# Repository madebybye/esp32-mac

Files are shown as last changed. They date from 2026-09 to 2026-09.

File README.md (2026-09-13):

# ESP32 Mac

A mini retro-Macintosh enclosure for the Waveshare
[ESP32-S3-Touch-AMOLED-1.8](https://www.waveshare.com/esp32-s3-touch-amoled-1.8.htm), designed in Fusion 360 and
printed in two parts with no hardware.

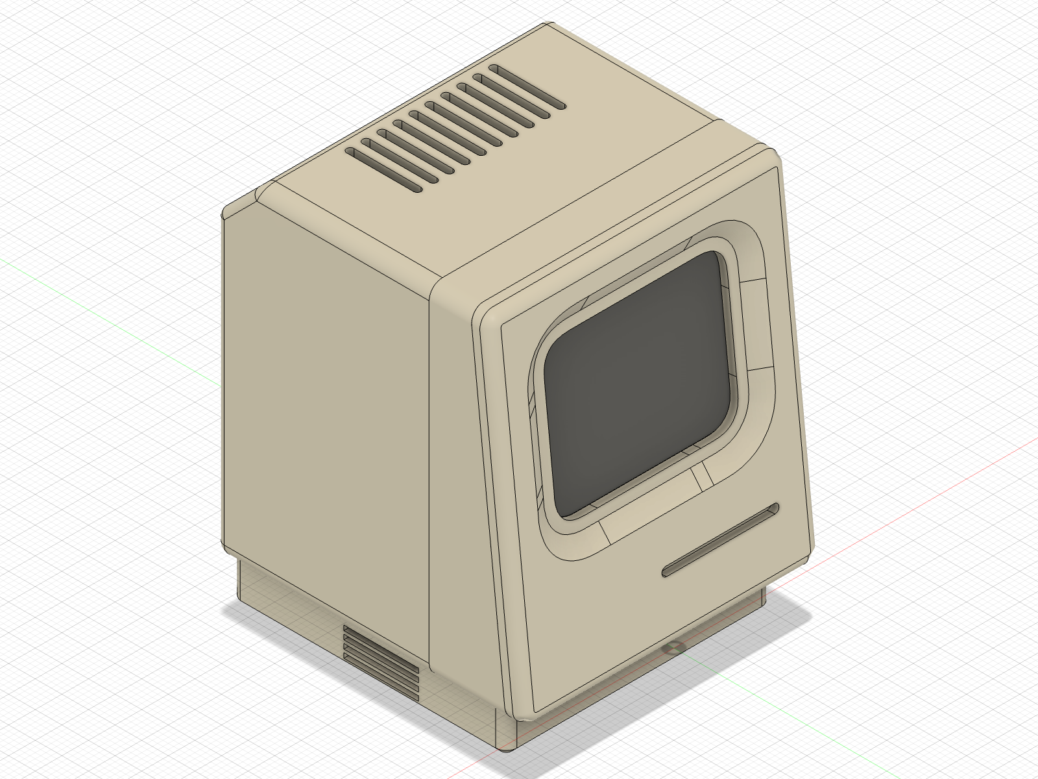
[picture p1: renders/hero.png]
ESP32 Mac


The board stays in its own case and drops into a pocket from the front, screen outwards. A separate face plate
presses onto six integrated pins (a dab of glue makes it permanent). A normal iPhone USB-C cable runs down a chute
inside the body and out through the foot, so nothing shows at the back. Warm air rises from behind the board through
a duct to the vent slots on top, and two grooves link the case's speaker and mic holes to the same duct.

## What you need

- The Waveshare ESP32-S3-Touch-AMOLED-1.8, in the case it ships in
- A normal iPhone USB-C cable (the Apple USB-C charge cable that comes with the phone). The plug cavity and chute
  are sized around its slim straight plug and thin cable, so bulkier or right-angle plugs may not fit.
- Optionally a dab of glue for the face plate

| | |
|---|---|
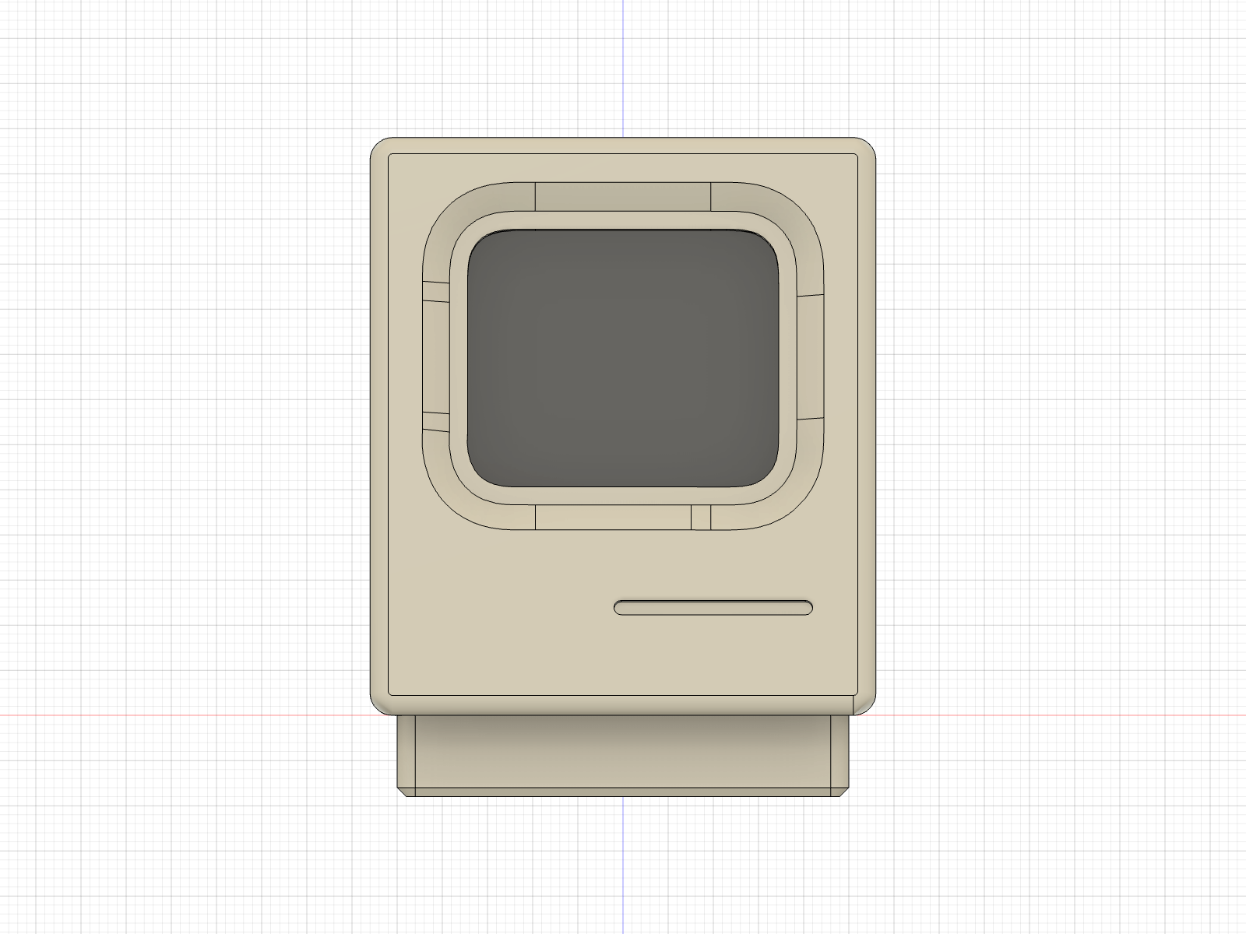
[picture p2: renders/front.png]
Front
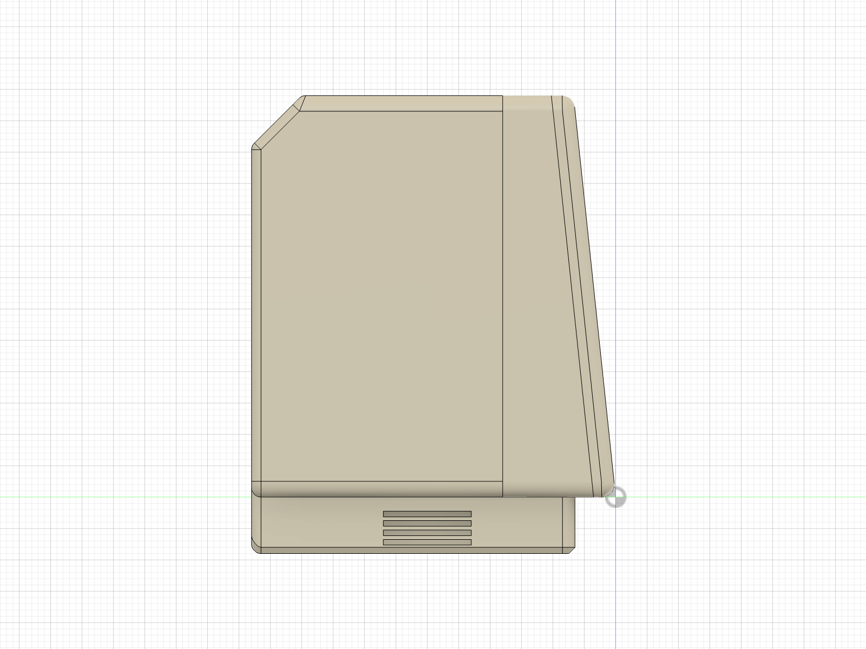
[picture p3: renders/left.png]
Side
|  |  |
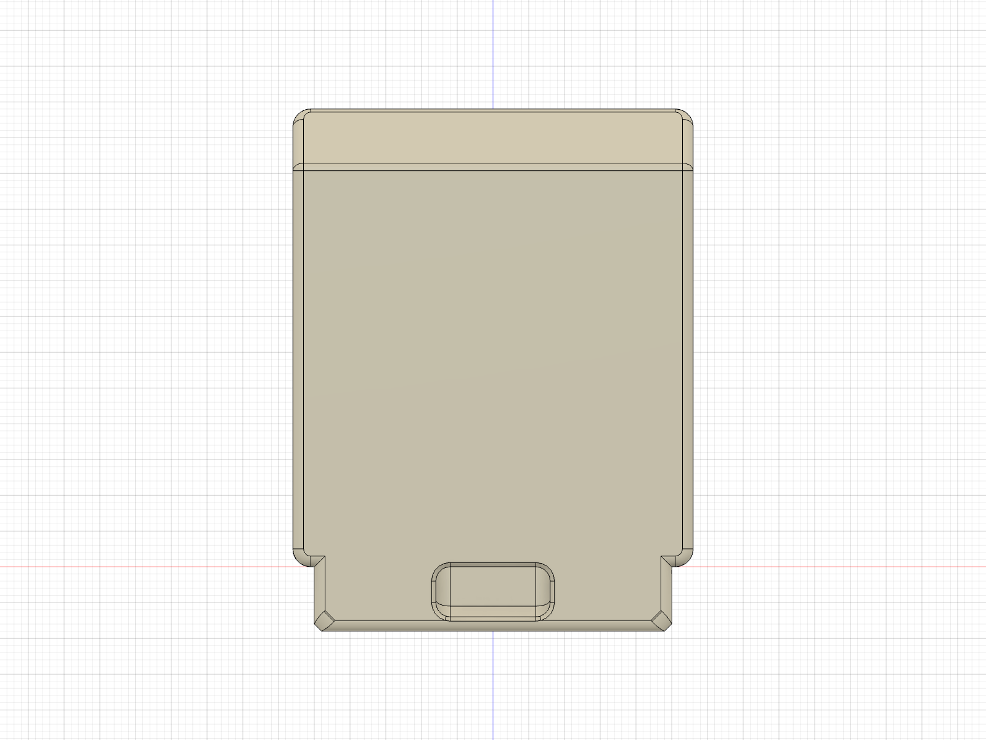
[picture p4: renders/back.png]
Back
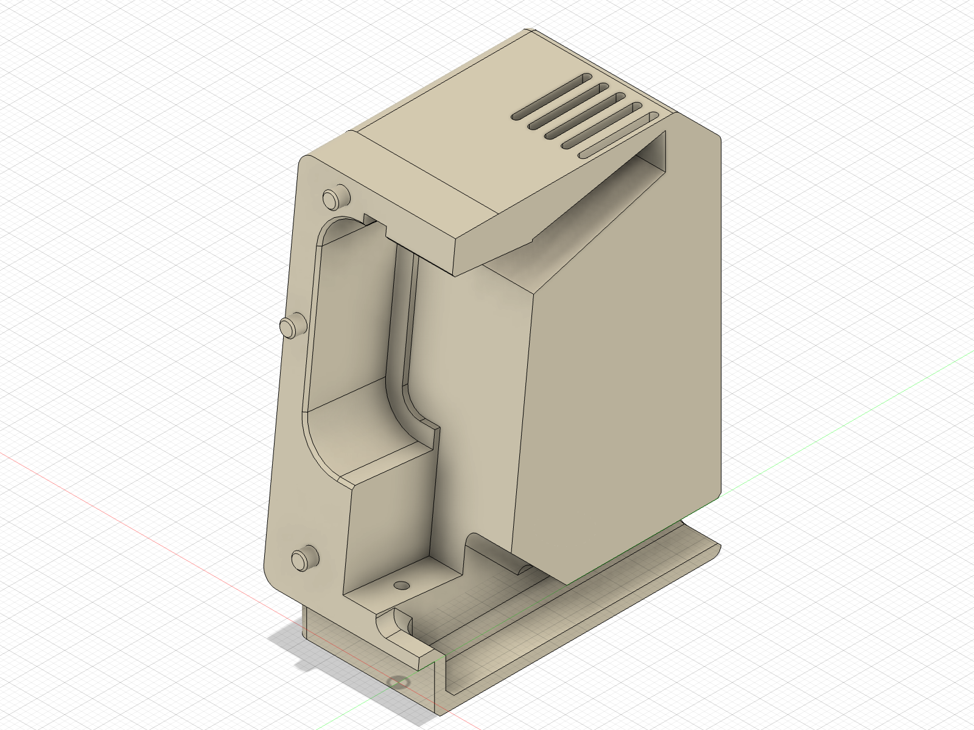
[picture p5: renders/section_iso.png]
Section
|  |  |

## Files

- `stl/` - print-ready `MiniMac_Body`, `MiniMac_FacePlate` and `MiniMac_FitGauge`
- `step/` - the same three parts as STEP
- `MiniMac.f3d` - the Fusion 360 design (it includes Waveshare's board model, imported from their wiki)
- `scripts/` - the Fusion API scripts that generate everything from one parameter block ([details](scripts/README.md))
- `renders/` - views, sections and a four-view sheet per part

## Printing

| Part | Orientation | Notes |
|---|---|---|
| Body | rear face down | 10-15 % infill, 5-6 top layers, supports on (tree) |
| FacePlate | face up | no supports; iron the top layer if you can |
| FitGauge | flat | 6 mm slab with the pocket and pins; print it first to check the fit |

0.12-0.16 mm layers, 3-4 walls. The body is 56 x 64 x 58 mm on a 9 mm foot, 73 mm tall overall.

The body needs supports: there is one internal overhang that won't print cleanly without them. Use tree supports if
your slicer has them. The face plate and the gauge print without supports.

The pocket is 45.4 x 37.7 mm for a case that measures 44.9 x 37.3, sized for a printer that comes out about 0.25 mm
tight per side. If the board is loose or won't go in, change `POCKET_W` and `POCKET_H` in `scripts/build.py` and
reprint the gauge.

## Assembly

Use a normal iPhone USB-C cable (see [What you need](#what-you-need)).

1. Feed the far end of the cable from the plug cavity down the chute, through the foot and out of the back.
2. Drop the board into the pocket with the screen facing outwards, towards the face plate.
3. Reach into the cavity and push the USB-C plug up into the socket.
4. Press the face plate onto the pins.

The board mounts landscape with its USB-C edge down, so rotate the UI 90 degrees in firmware.

## Rebuilding the model

`scripts/build.py` regenerates all three parts from the parameters at its top: pocket size, wall thicknesses, vents,
cable route. It needs Fusion 360 with Waveshare's 3D model imported. Download `ESP32-S3-Touch-AMOLED-1.8-3D.zip`
from the [Waveshare wiki](https://www.waveshare.com/wiki/ESP32-S3-Touch-AMOLED-1.8), unzip the `.stp` into
`reference/`, then run `import_step.py`, `build.py`, `checks.py` and `export.py` in that order from Fusion's Scripts
panel.

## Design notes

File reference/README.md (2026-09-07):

Waveshare's 3D model of the board goes here and is not included in this repository.

Download `ESP32-S3-Touch-AMOLED-1.8-3D.zip` from the resources section of the
[Waveshare wiki](https://www.waveshare.com/wiki/ESP32-S3-Touch-AMOLED-1.8) and unzip
`ESP32-S3-Touch-AMOLED-1.8-3D.stp` into this folder. `scripts/import_step.py` imports it.

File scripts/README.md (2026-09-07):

Fusion 360 API scripts. Each defines `run(context)`; run them from Fusion's Scripts and Add-Ins panel (or through a
Fusion MCP server, in which case define `__file__` first so the scripts can find the repo folder).

1. `import_step.py` - imports `../reference/ESP32-S3-Touch-AMOLED-1.8-3D.stp` (Waveshare's board model) into an empty design.
2. `build.py` - rebuilds FacePlate, Body and FitGauge from the parameters at its top. Safe to re-run: it deletes the
   previous parts, re-places the board and rebuilds.
3. `checks.py` - interference and ray-cast checks. One interference is expected: the pocket is cut 0.4 mm shallower
   than the case, so the face plate holds the board on the pocket's floor rim.
4. `export.py` - writes `../MiniMac.f3d`, `../stl/MiniMac_<part>.stl` and `../step/MiniMac_<part>.step`.

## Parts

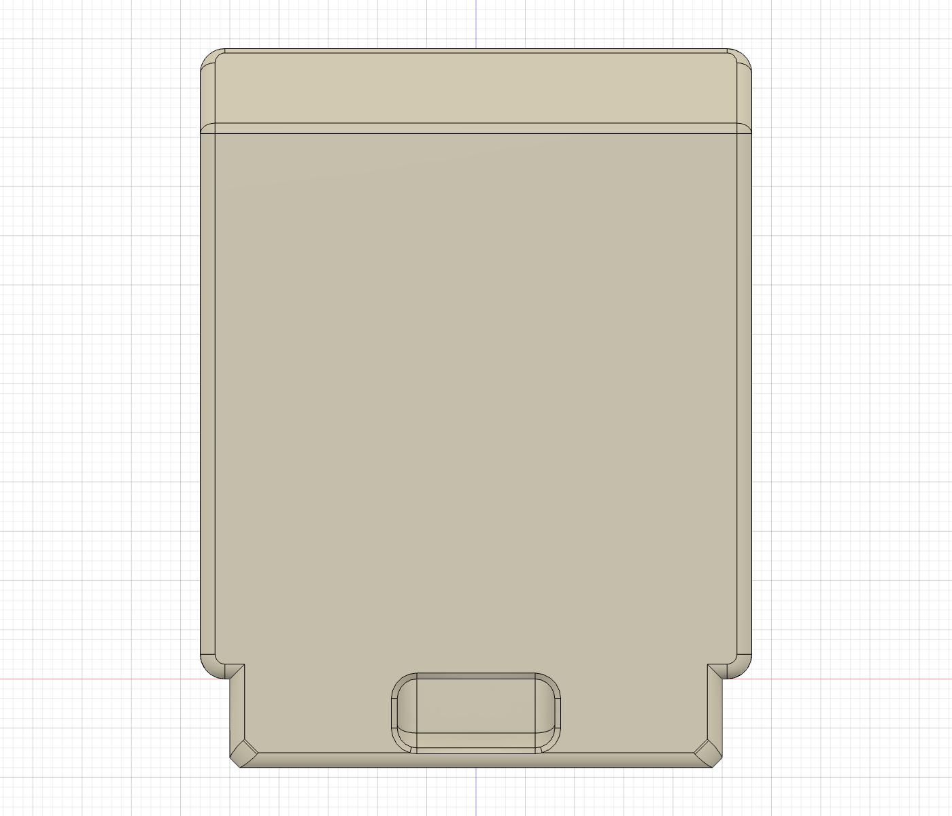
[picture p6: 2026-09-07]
renders/parts/Body_back.png

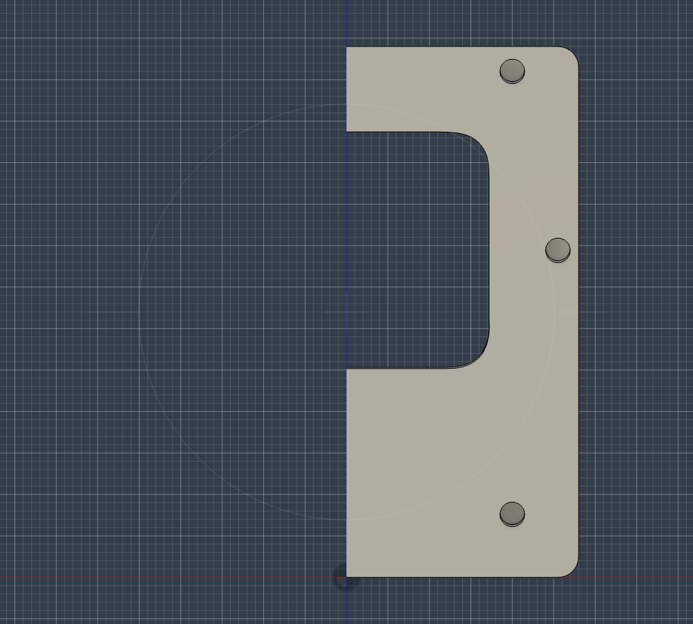
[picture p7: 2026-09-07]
renders/parts/FacePlate_back.png

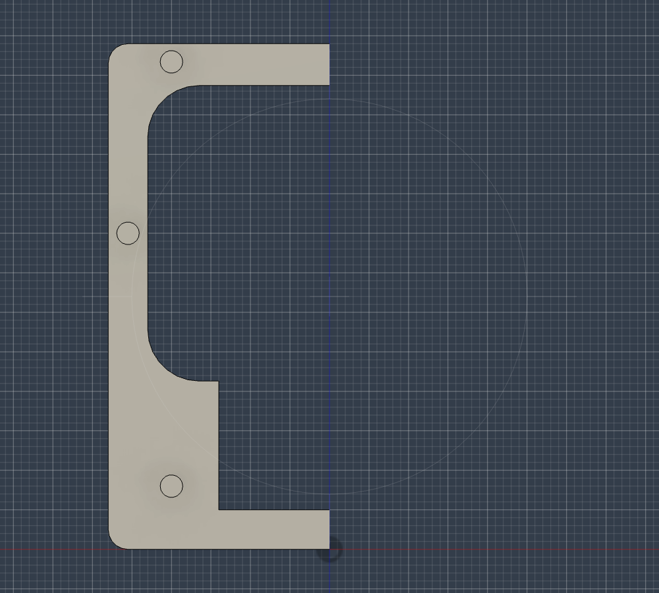
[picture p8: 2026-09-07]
renders/parts/FitGauge_front.png

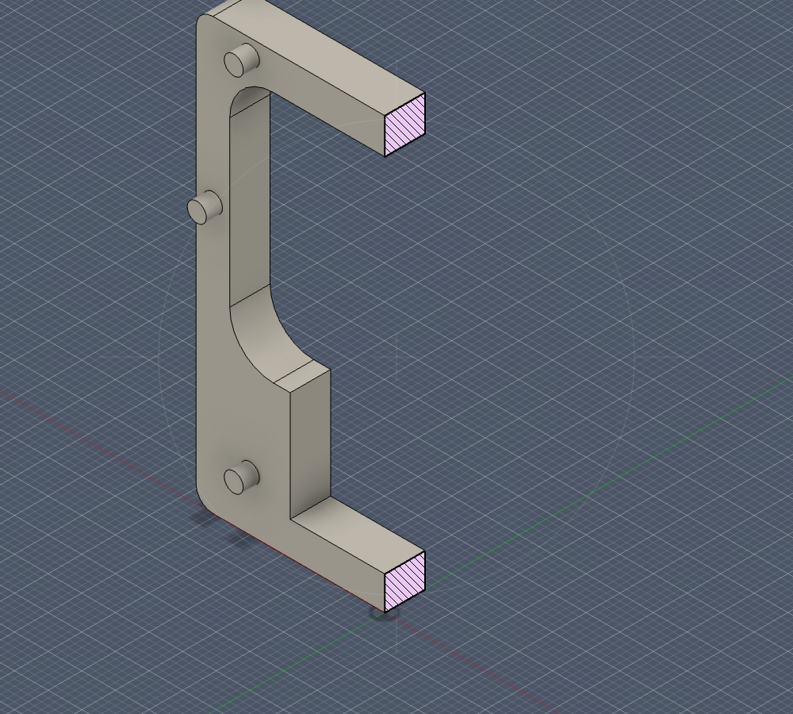
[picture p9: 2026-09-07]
renders/parts/FitGauge_iso-top-right.png

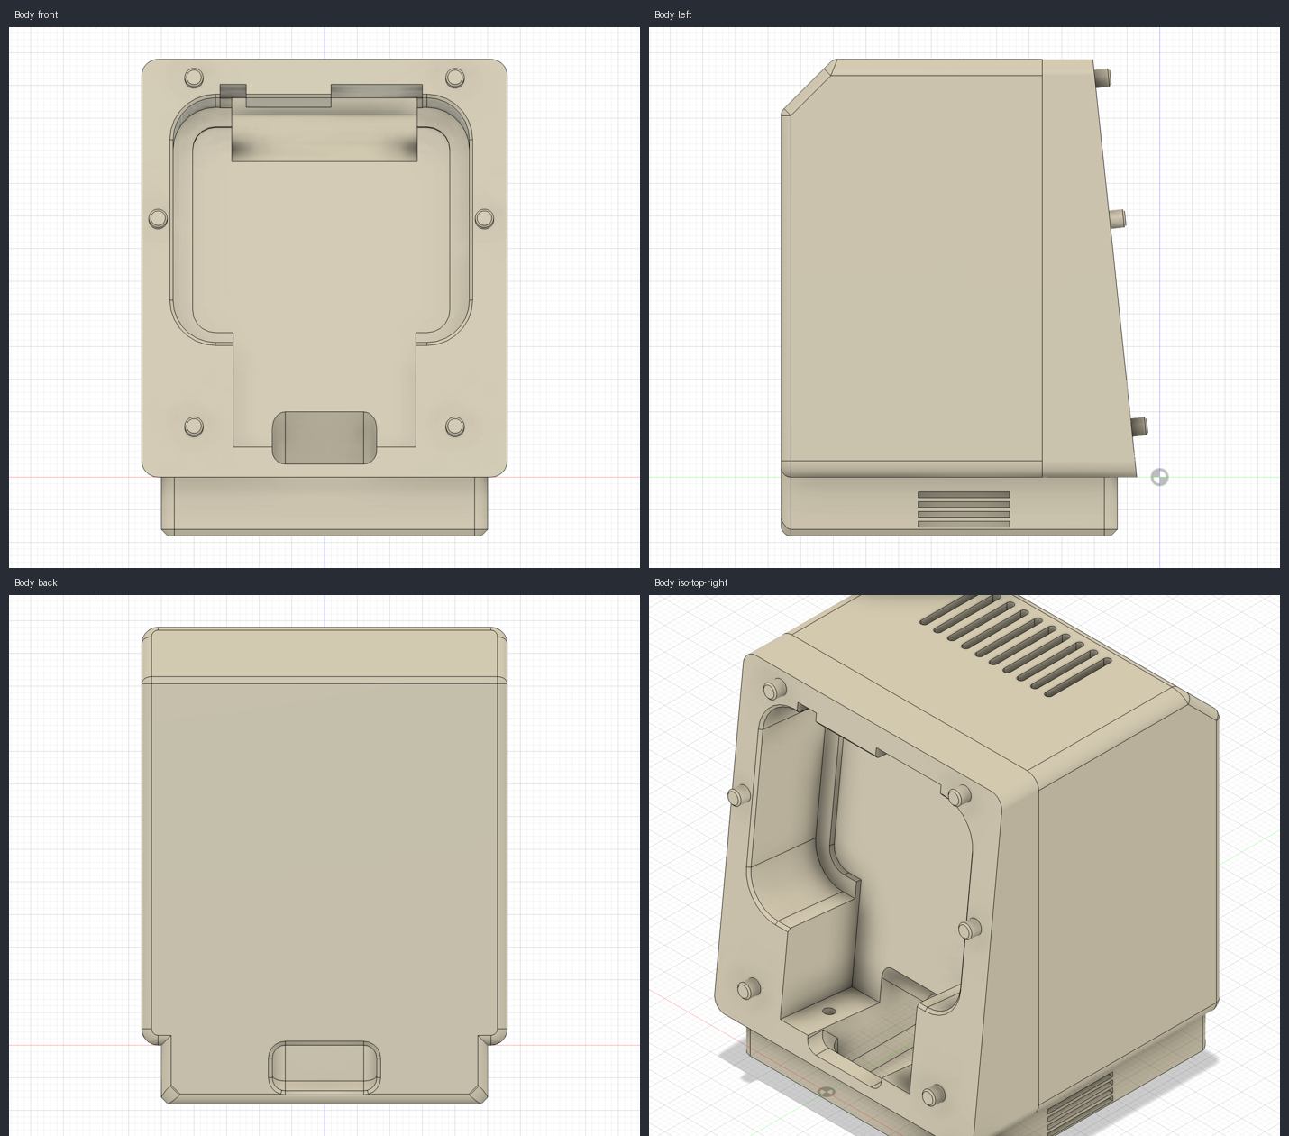
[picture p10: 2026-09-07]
renders/parts/Body_sheet.png

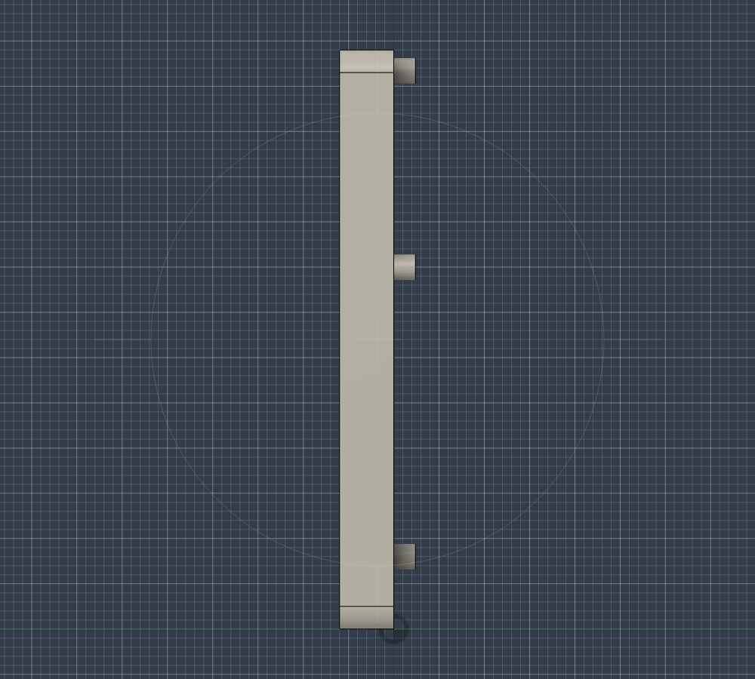
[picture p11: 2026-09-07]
renders/parts/FitGauge_left.png

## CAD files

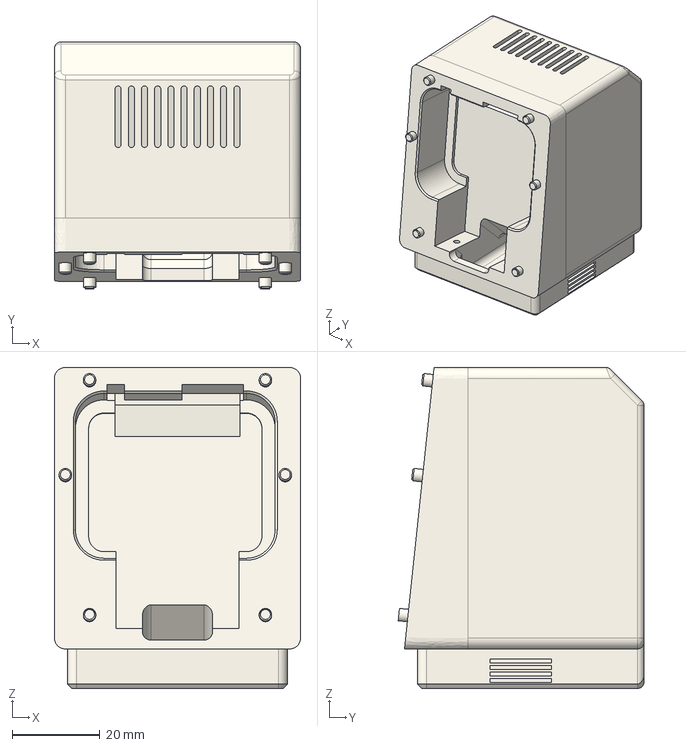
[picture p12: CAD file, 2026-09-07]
step/MiniMac_Body.step
56.0 x 56.2 x 73.0 mm

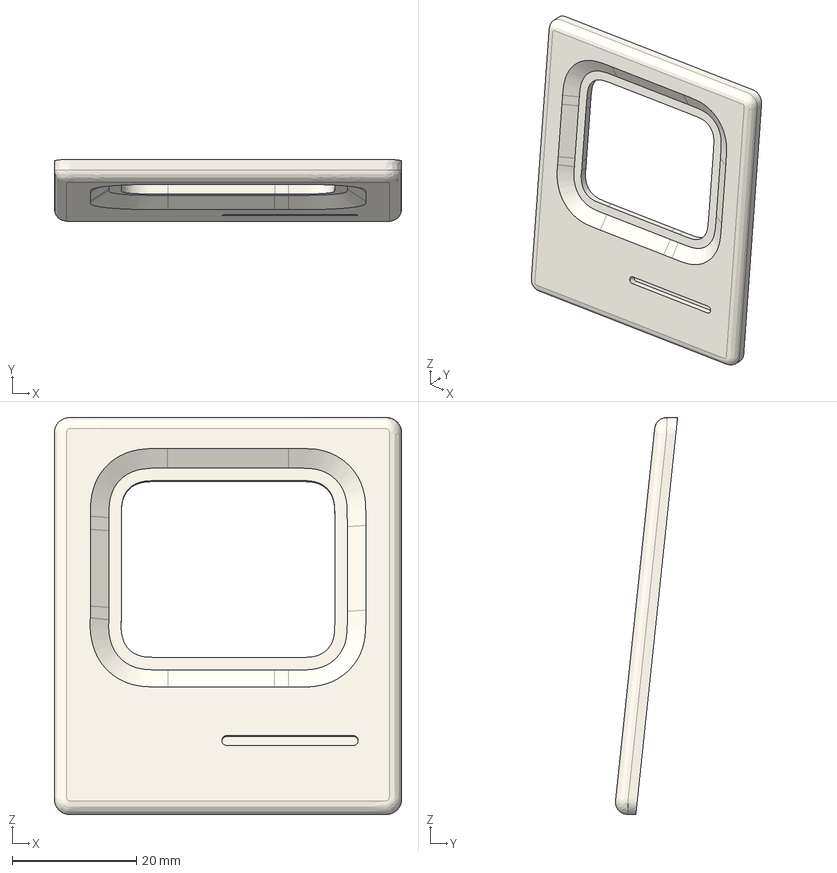
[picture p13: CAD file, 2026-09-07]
step/MiniMac_FacePlate.step
56.0 x 10.0 x 64.0 mm

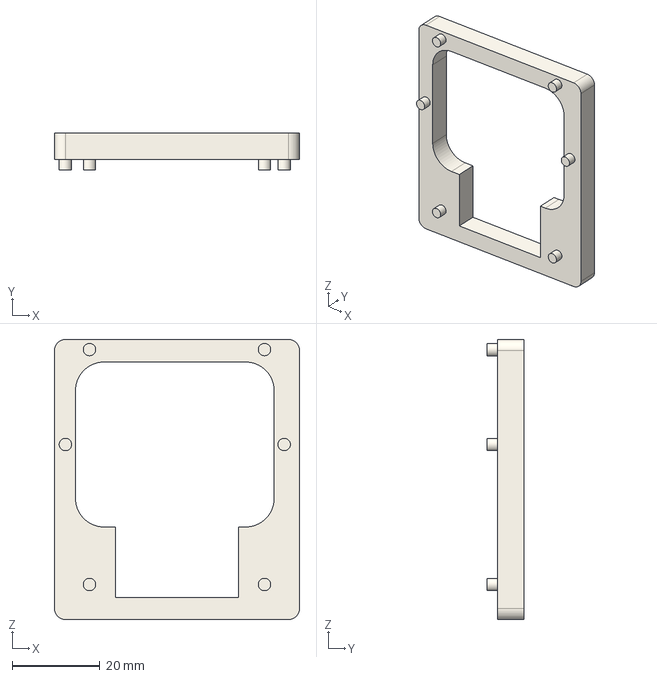
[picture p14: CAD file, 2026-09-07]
step/MiniMac_FitGauge.step
56.0 x 8.40 x 64.0 mm

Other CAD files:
MiniMac.f3d
stl/MiniMac_Body.stl
stl/MiniMac_FacePlate.stl
stl/MiniMac_FitGauge.stl

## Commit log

2026-09-07 ESP32 Mac: mini retro Macintosh enclosure for the Waveshare ESP32-S3-Touch-AMOLED-1.8
    Two 3D-printed parts plus a fit gauge, generated parametrically in Fusion 360 by the
    scripts in scripts/. Print-ready STLs and STEPs, the Fusion archive, renders, and a
    short README. Waveshare's board model is not included; the README says where to get it.
    [MiniMac.f3d, MiniMac_Body.step, MiniMac_Body.stl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]
2026-09-13 README: body needs tree supports, screen-outwards and cable notes (#1)
    The body has one internal overhang, so the printing table now says to
    turn supports on (tree preferred) instead of "no supports"; the intro no
    longer claims a support-free print.
    Assembly now says to drop the board in screen outwards, and both the
    intro and a new "What you need" section call out a normal iPhone USB-C
    cable, since the plug cavity and chute are sized around its straight
    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
